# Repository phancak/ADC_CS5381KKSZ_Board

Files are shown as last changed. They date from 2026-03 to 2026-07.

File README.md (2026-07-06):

# 24-bit High-Fidelity Data Acquisition System
### High-SNR Analog Front-End & Mixed-Signal Instrumentation Platform

<div align="center">
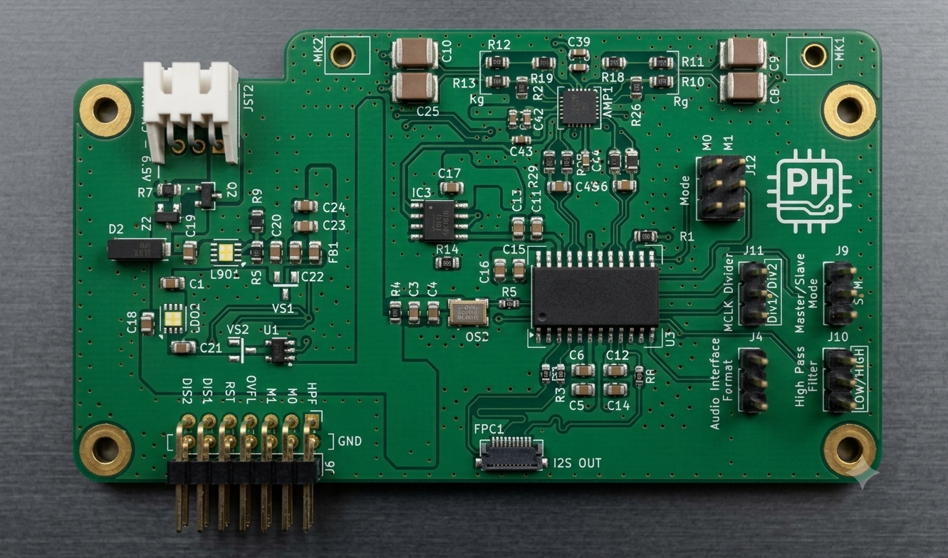
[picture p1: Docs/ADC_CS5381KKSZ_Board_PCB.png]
ADC CS5381KKSZ Board PCB 3D Render
  
  <br>
  <em>ADC CS5381KKSZ 4-layer PCB diagram.</em>
</div>

## 📑 Quick Access
* [**📂 View Project Schematics (PDF)**](./Schematics/ADC_CS5381KKSZ_Board_Schematics.pdf)

## 🚀 Overview
This project is a custom-designed, high-precision Analog-to-Digital Conversion (ADC) board optimized for professional audio and precision instrumentation. It utilizes a fully differential signal chain to maximize dynamic range and minimize common-mode noise, making it suitable for high-EMI environments.

## 🛠 Core Component Selection
* **ADC:** **CS5381K-KSZ** (120dB Dynamic Range, 24-bit, 192kHz sampling). A flagship Delta-Sigma converter.
* **Front-End Driver:** **ADA4940-2** Ultra-low noise, fully differential amplifier.
* **Sensors:** 2x **ICS-40730** Bottom-Port MEMS Microphones with 74dB SNR for high-definition acoustic capture.

---

## 🏗 Key Engineering Challenges & Solutions

### 1. Differential Signal Integrity
To leverage the 120dB SNR of the CS5381, I implemented a fully differential path from the amplifier to the ADC.
* **The Challenge:** Converting single-ended sensor signals while maintaining a -122dB SFDR.
* **The Solution:** Used the **ADA4940-2** to provide a stable common-mode voltage and high linearity, ensuring the ADC inputs stay within the optimal swing range.

### 2. Precision Length Matching (Via Compensation)
In high-speed mixed-signal design, phase coherency between channels is critical.
* **Via Propagation Delay:** One of my analog traces required two vias (unavoidable). To prevent phase shift, I calculated the vertical travel distance through the 1.6mm PCB stackup and compensated the "via-free" traces by adding **3.2mm of serpentine meanders**.
* **Tolerance:** Achieved sub-0.5mm effective electrical length matching across all high-priority analog traces.

### 3. Power Integrity & EMI Shielding
* **Copper Pours:** Utilized large 3.3V and 5V copper polygons on the top layer to minimize **IR drop** and **loop inductance**. 
* **Isolation:** Strategically distanced power pours from high-speed digital lines to prevent capacitive crosstalk. 
## 🏗 Grounding & Power Integrity Strategy
Unlike traditional "Split Plane" designs, this board utilizes a **Solid Ground Plane** strategy on internal layers 2 and 3 to ensure the lowest possible impedance for return currents.

* **Low-Inductance Return Paths:** By maintaining a continuous ground plane under the analog and digital sections, I minimized the loop area for high-speed I2S signals, preventing ground-bounce and radiated emissions.
* **Component Partitioning:** Rather than a physical split in the copper, I used **Spatial Isolation**. Analog components (ADA4940, CS5381 input stage) are physically grouped on one side of the board, while digital I/O and the STM32 interface are on the opposite side, ensuring digital return currents do not traverse the sensitive analog "quiet zone."
* **Layer Stackup:**
    * Layer 1: Signal / Power Pours
    * Layer 2: **GND (Solid Reference)**
    * Layer 3: **GND (Solid Reference)**
    * Layer 4: Signal / Power Pours
---

## 👨‍💻 About Me
I am an Engineering Graduate from the **University of British Columbia (UBC)**. I specialize in the intersection of Embedded Systems and Data Engineering. Whether it's designing 6-DoF robotic arms or high-fidelity ADC boards, I focus on "First Principles" engineering—calculating via delays, optimizing power pours, and ensuring data integrity from the sensor to the report.

---

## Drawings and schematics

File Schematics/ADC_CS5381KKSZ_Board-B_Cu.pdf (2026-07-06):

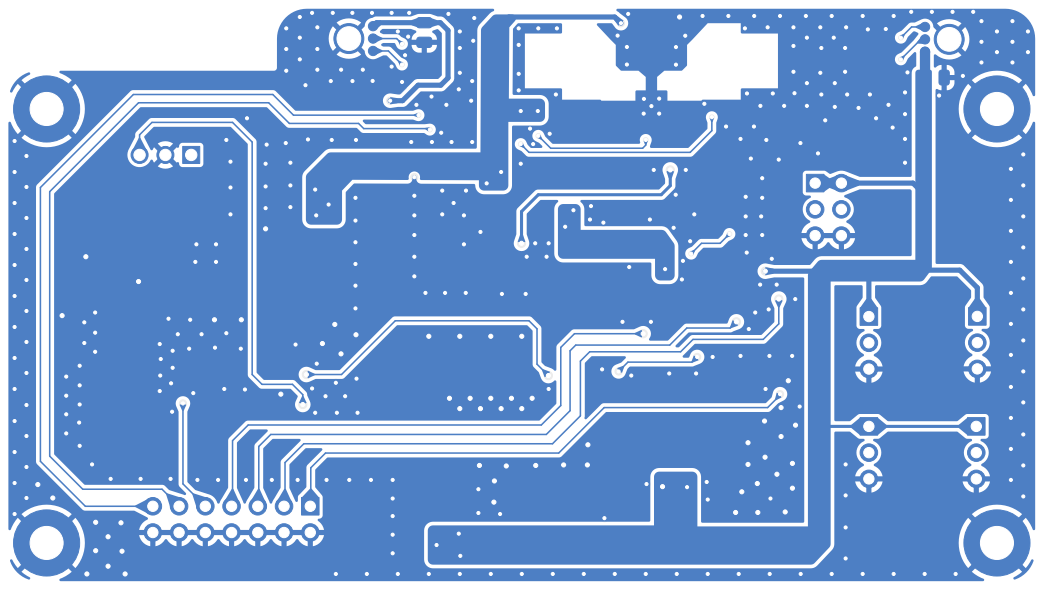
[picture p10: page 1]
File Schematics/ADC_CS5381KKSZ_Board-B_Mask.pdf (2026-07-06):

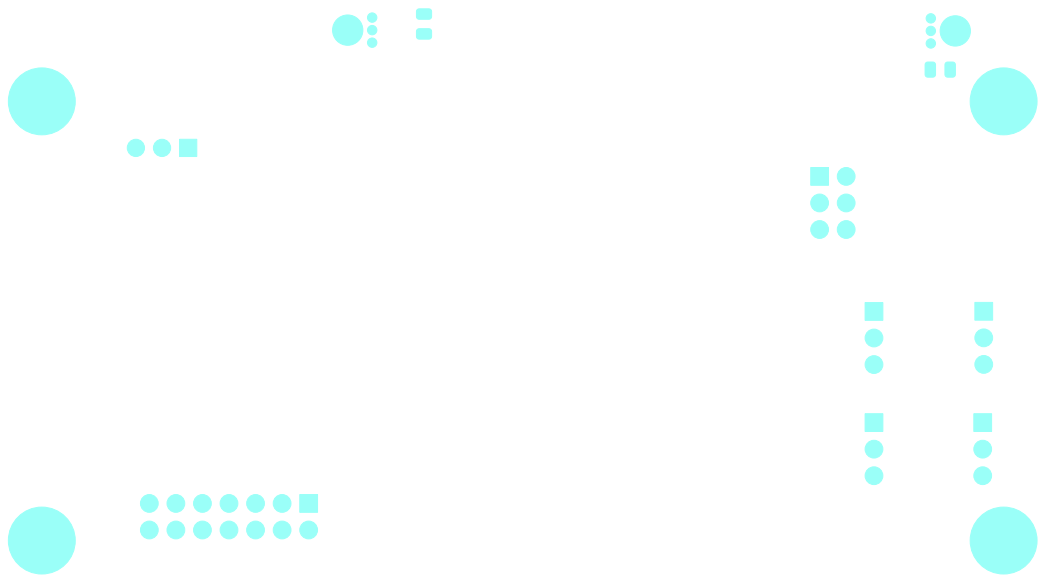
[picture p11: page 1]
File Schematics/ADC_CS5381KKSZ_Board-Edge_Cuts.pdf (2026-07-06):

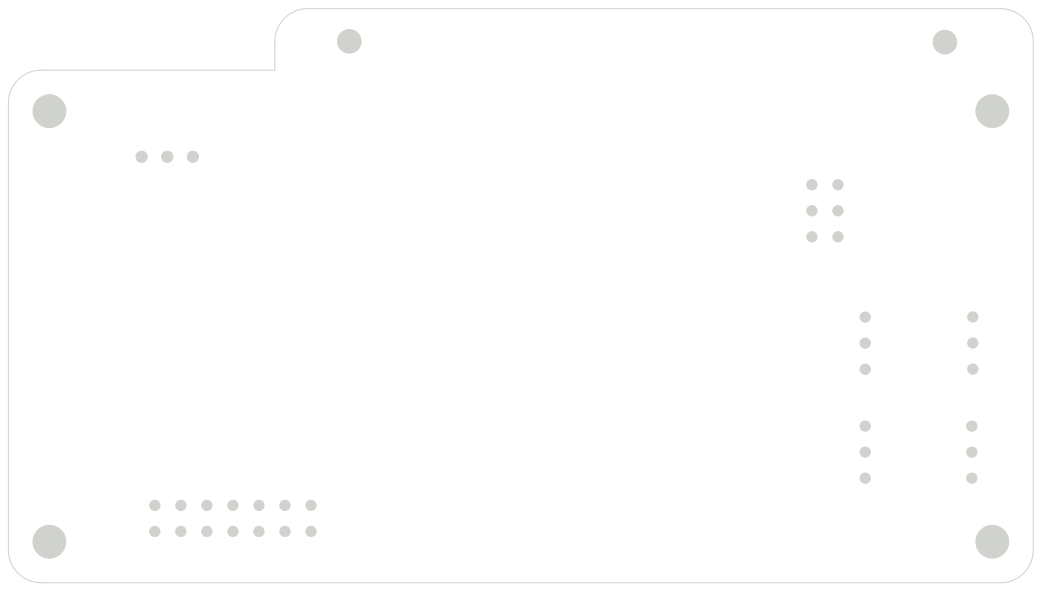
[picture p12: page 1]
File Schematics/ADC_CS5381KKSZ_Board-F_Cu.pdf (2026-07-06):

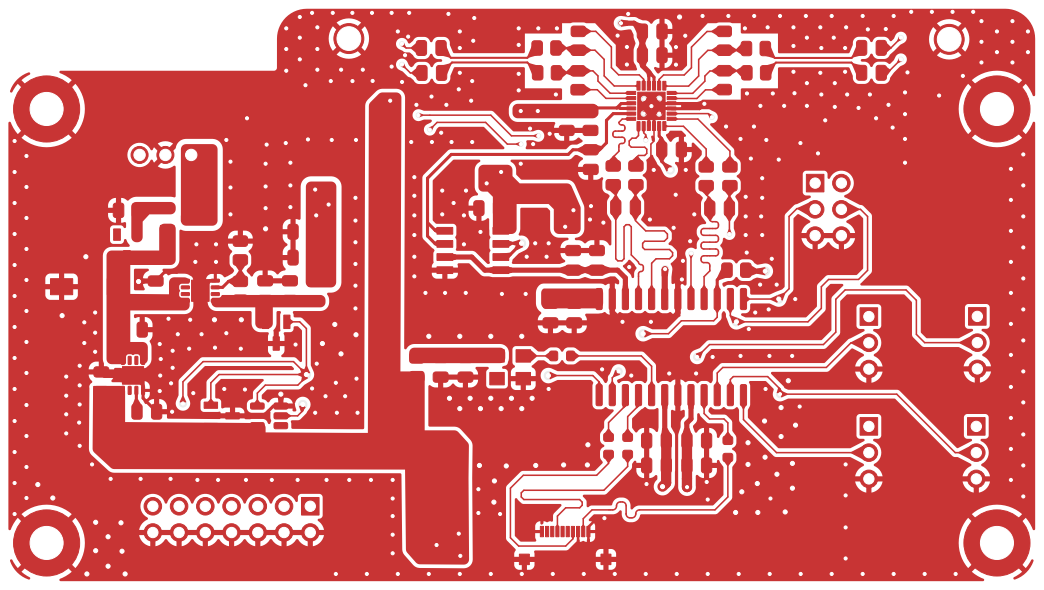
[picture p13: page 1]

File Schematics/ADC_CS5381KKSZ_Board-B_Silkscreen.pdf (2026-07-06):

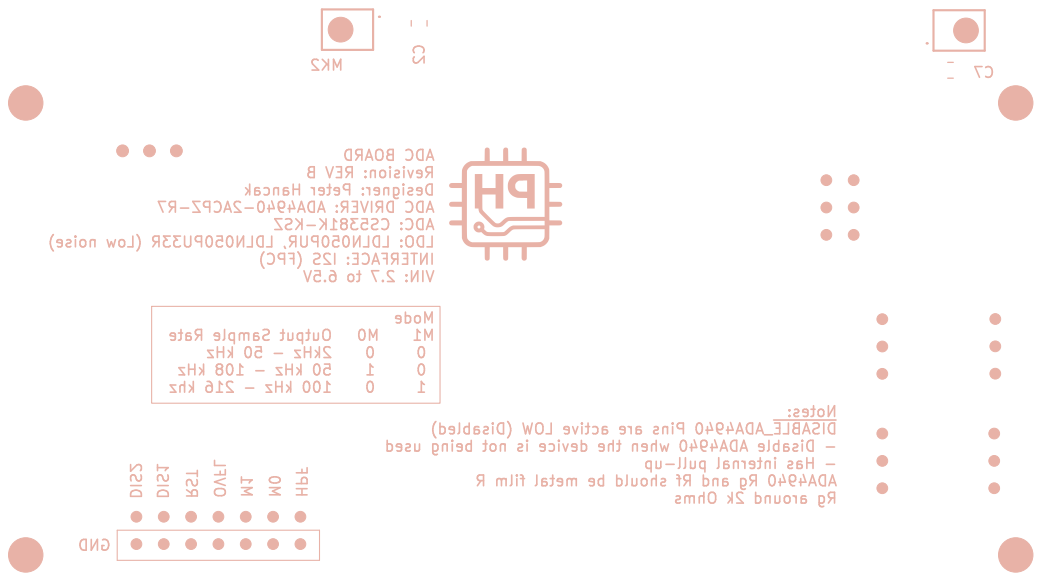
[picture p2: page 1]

used being not is device the when ADA4940 Disable - pull-up internal Has - R film metal be should Rf and Rg ADA4940 Ohms 2k around Rg M1 MK2 C7 C2

OVFL M0 GND RST BOARD ADC

B REV Revision: Hancak Peter Designer: ADA4940-2ACPZ-R7 DRIVER: ADC

CS5381K-KSZ ADC: noise) (Low LDLN050PU33R LDLN050PUR, LDO: (FPC) I2S INTERFACE: 6.5V to 2.7 VIN: HPF Mode Rate Sample Output M0 M1

khz 216 - kHz 100 0 1 DIS2 DIS1 Notes: (Disabled) LOW active are Pins ~{DISABLE}_ADA4940

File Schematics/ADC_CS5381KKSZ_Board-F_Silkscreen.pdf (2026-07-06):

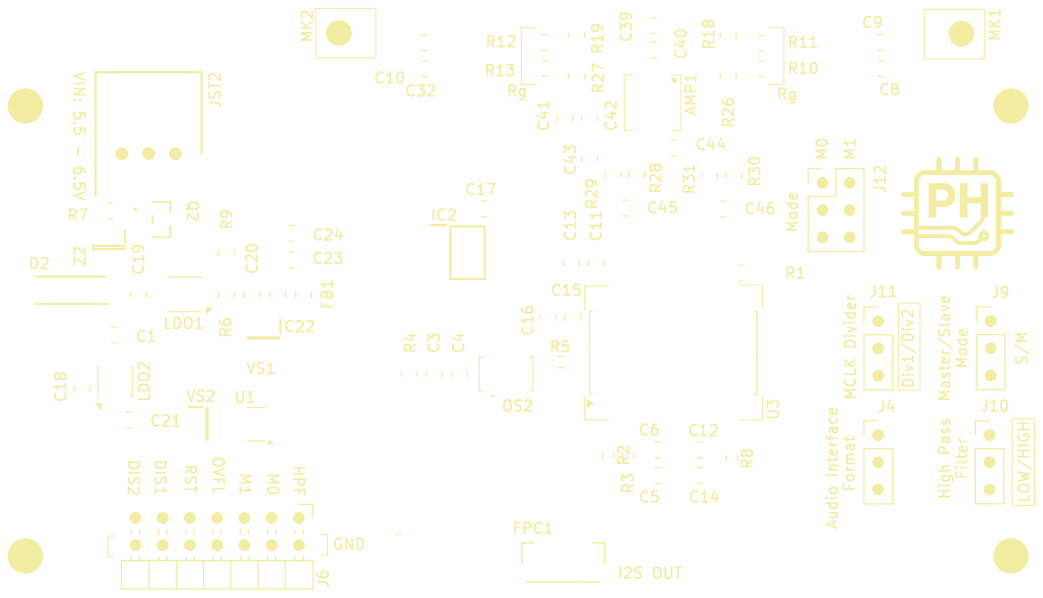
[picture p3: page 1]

LOW/HIGH MK2 M1 OVFL M0 Div1/Div2 High Pass Filter MCLK Divider Audio Interface Format RST Master/Slave Mode M0

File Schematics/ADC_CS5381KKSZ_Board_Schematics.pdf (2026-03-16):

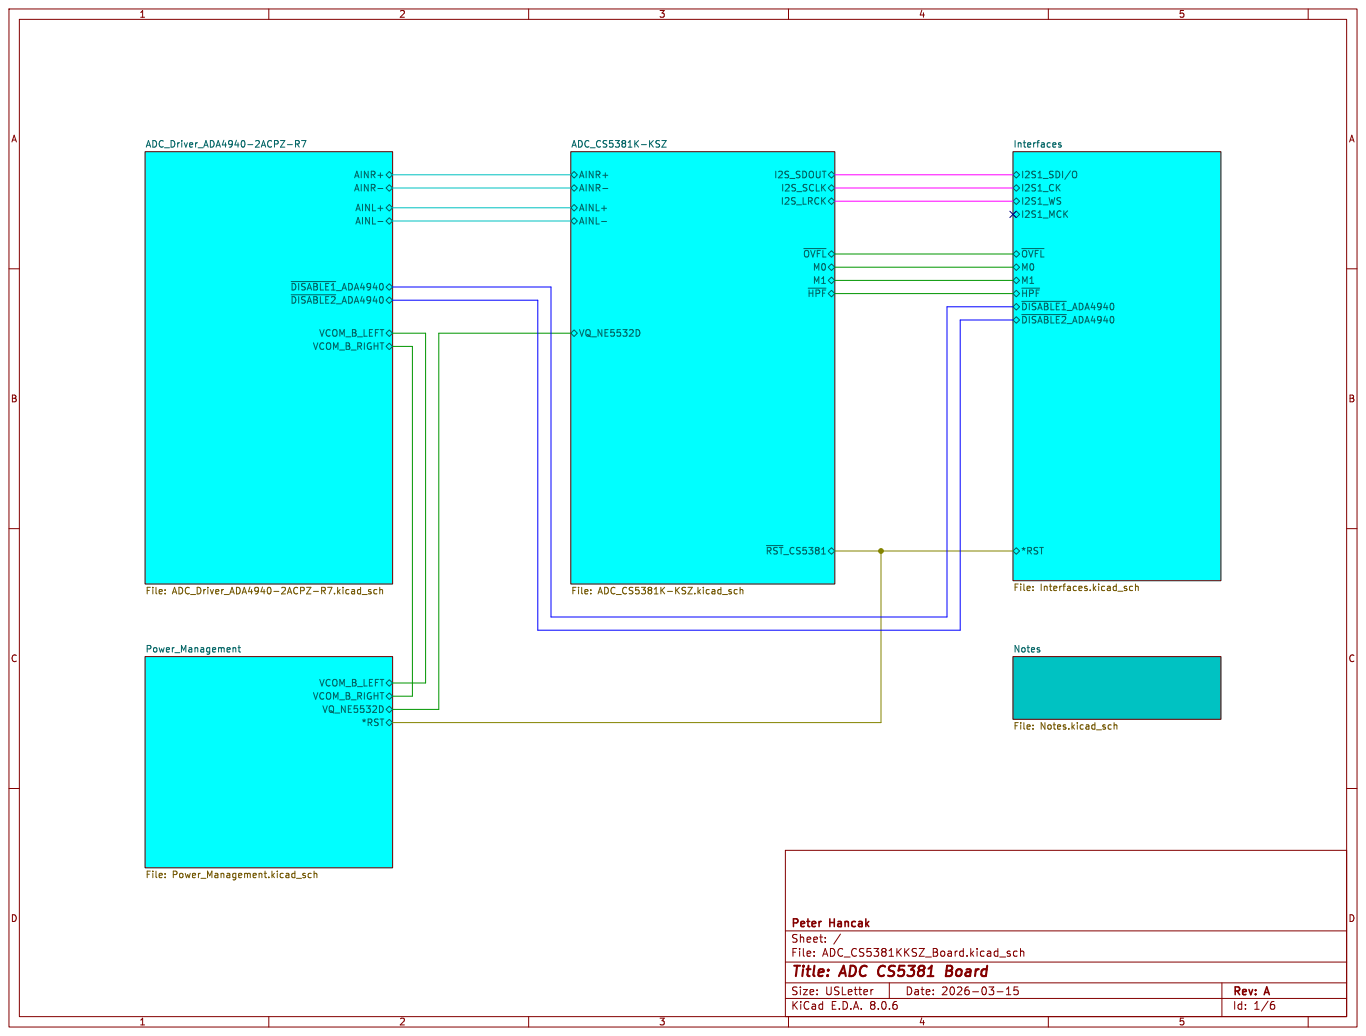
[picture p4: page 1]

Id: 1/6 Title: ADC CS5381 Board

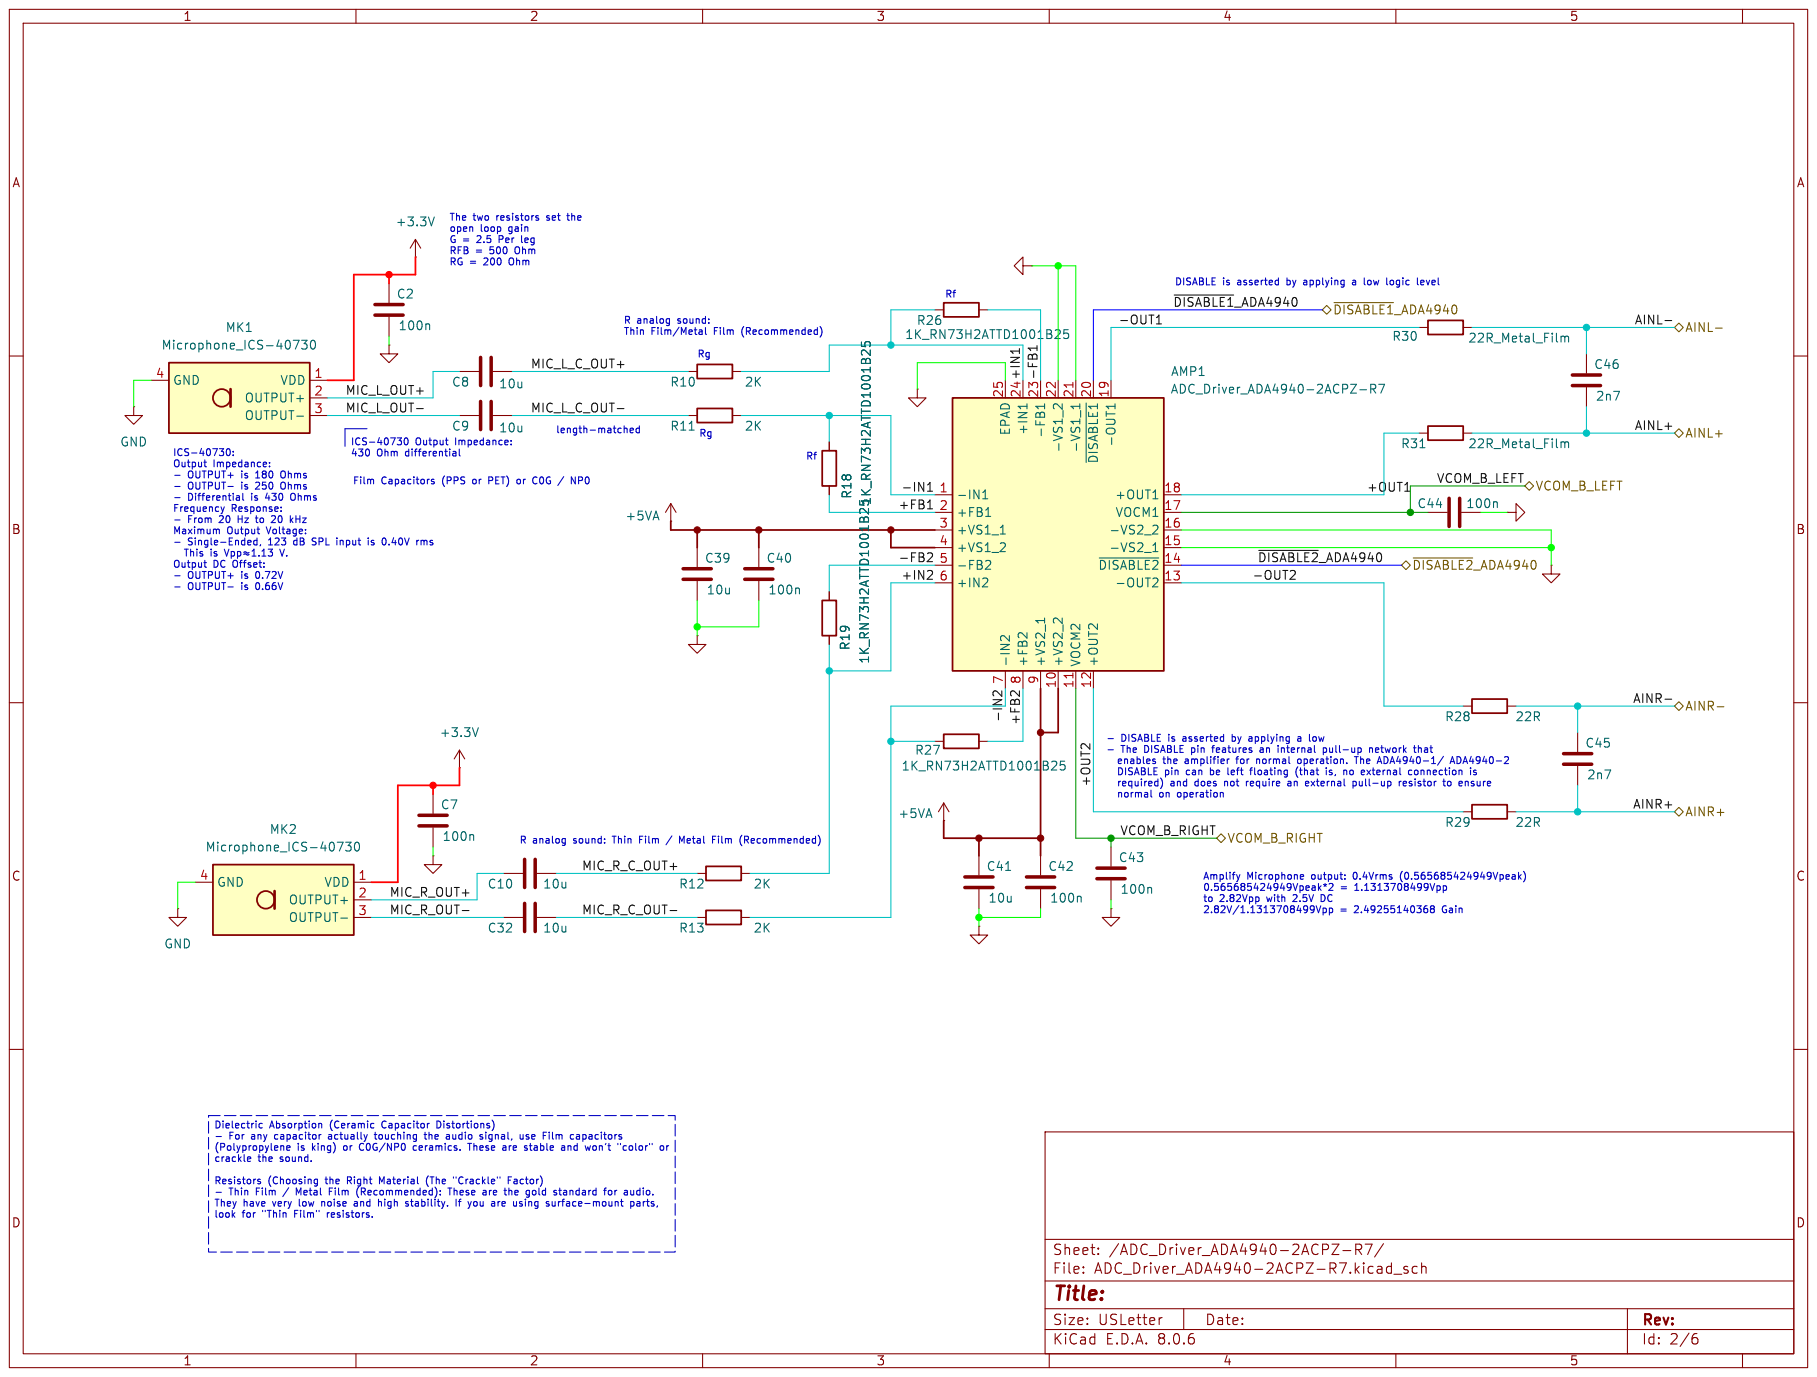
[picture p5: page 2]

open loop gain G = 2.5 Per leg RFB = 500 Ohm

ICS-40730: Output Impedance: - OUTPUT+ is 180 Ohms

Id: 2/6 Title: File: ADC_Driver_ADA4940-2ACPZ-R7.kicad_sch Sheet: /ADC_Driver_ADA4940-2ACPZ-R7/

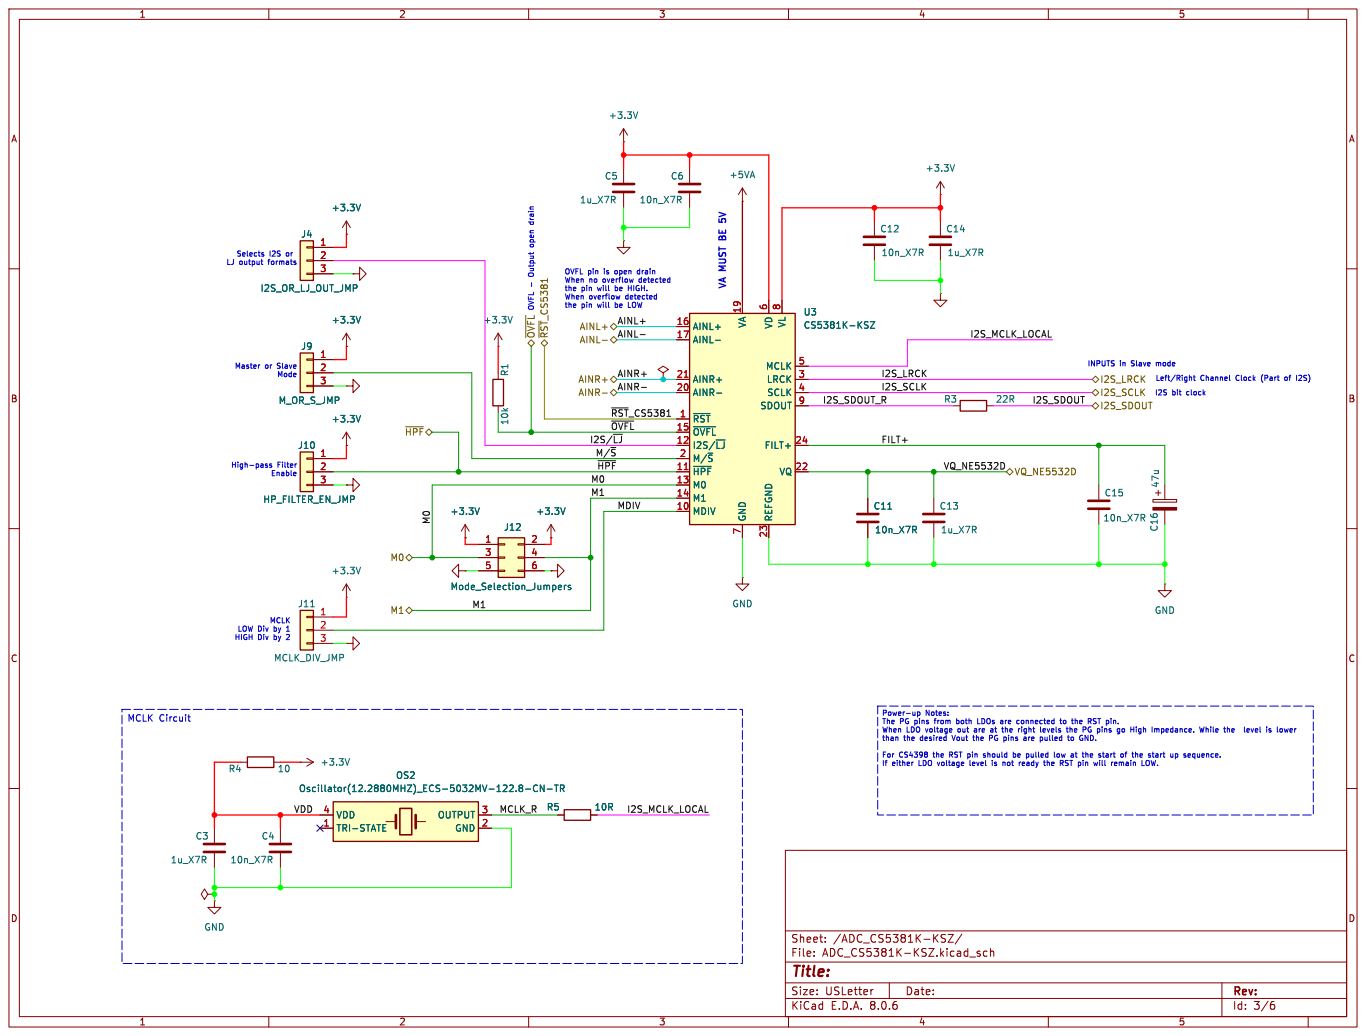
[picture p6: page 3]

- Output open drain Power-up Notes: The PG pins from both LDOs are connected to the RST pin. When LDO voltage out are at the right levels the PG pins go High Impedance. While the level is lower

~{RST}_CS5381 AINR- AINL+ AINL-
I2S_MCLK_LOCAL M0M/~{S}MDIV

INPUTS in Slave mode
I2S_LRCK

Id: 3/6 Title: File: ADC_CS5381K-KSZ.kicad_sch Sheet: /ADC_CS5381K-KSZ/ GND

than the desired Vout the PG pins are pulled to GND. For CS4398 the RST pin should be pulled low at the start of the start up sequence.

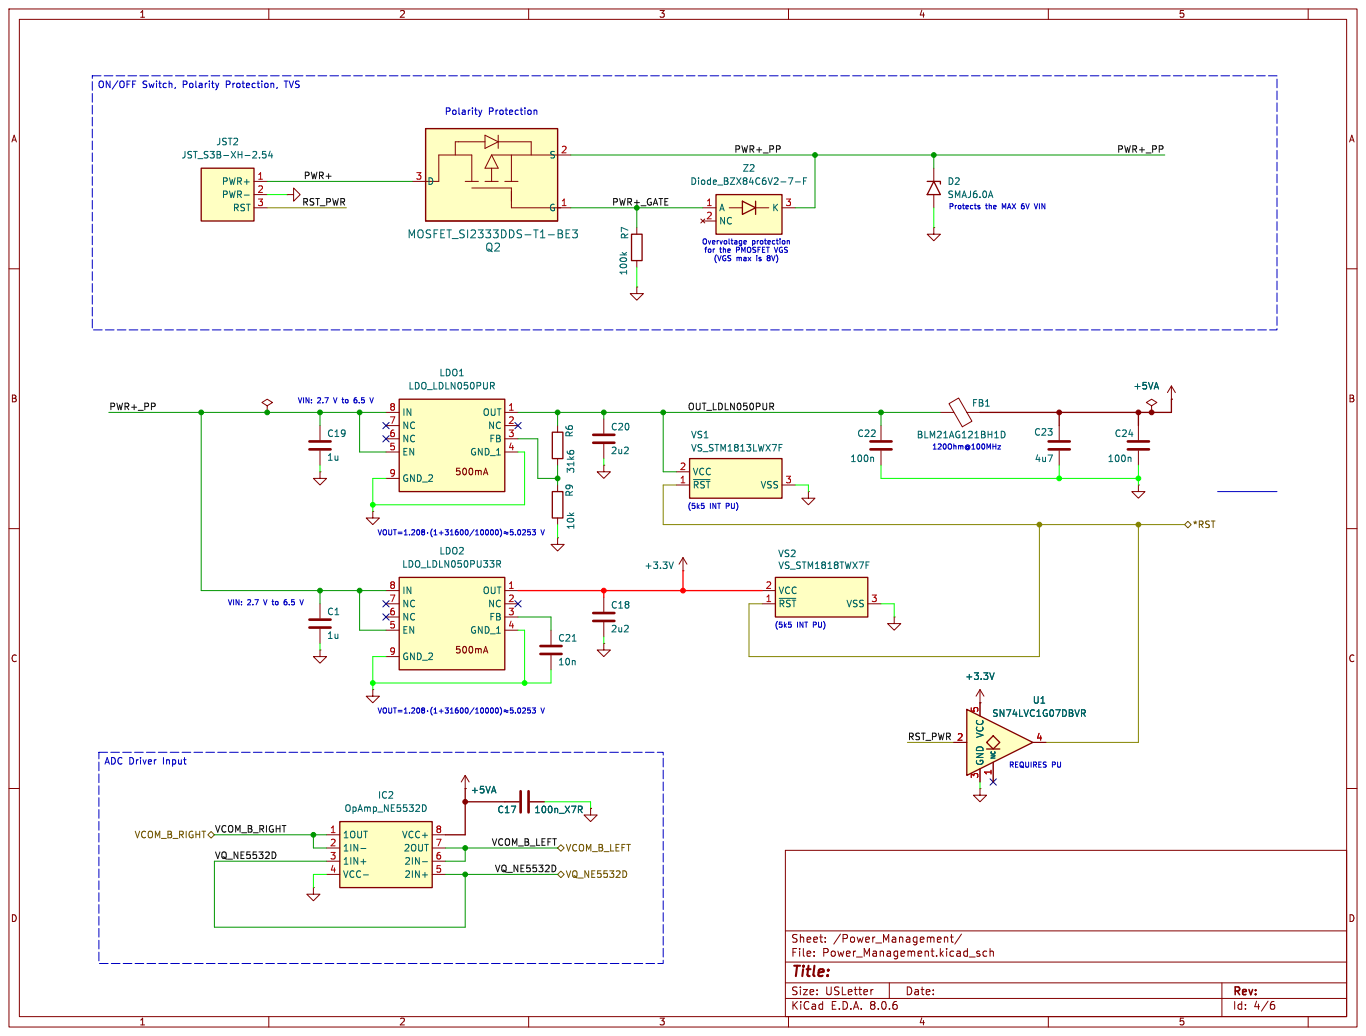
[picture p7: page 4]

for the PMOSFET VGS

Id: 4/6 Title: File: Power_Management.kicad_sch Sheet: /Power_Management/

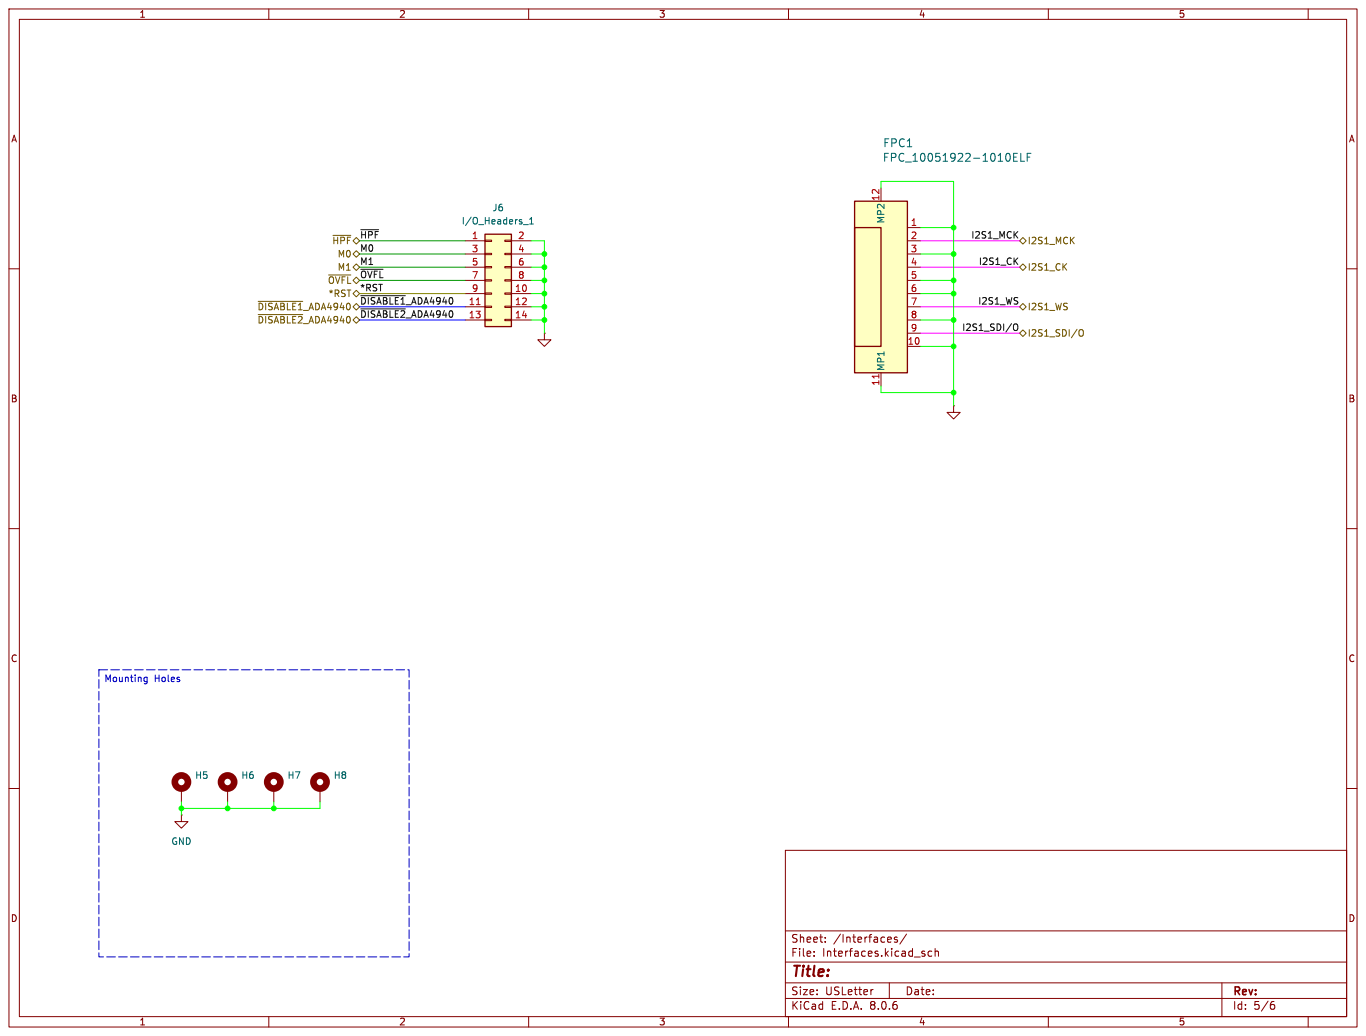
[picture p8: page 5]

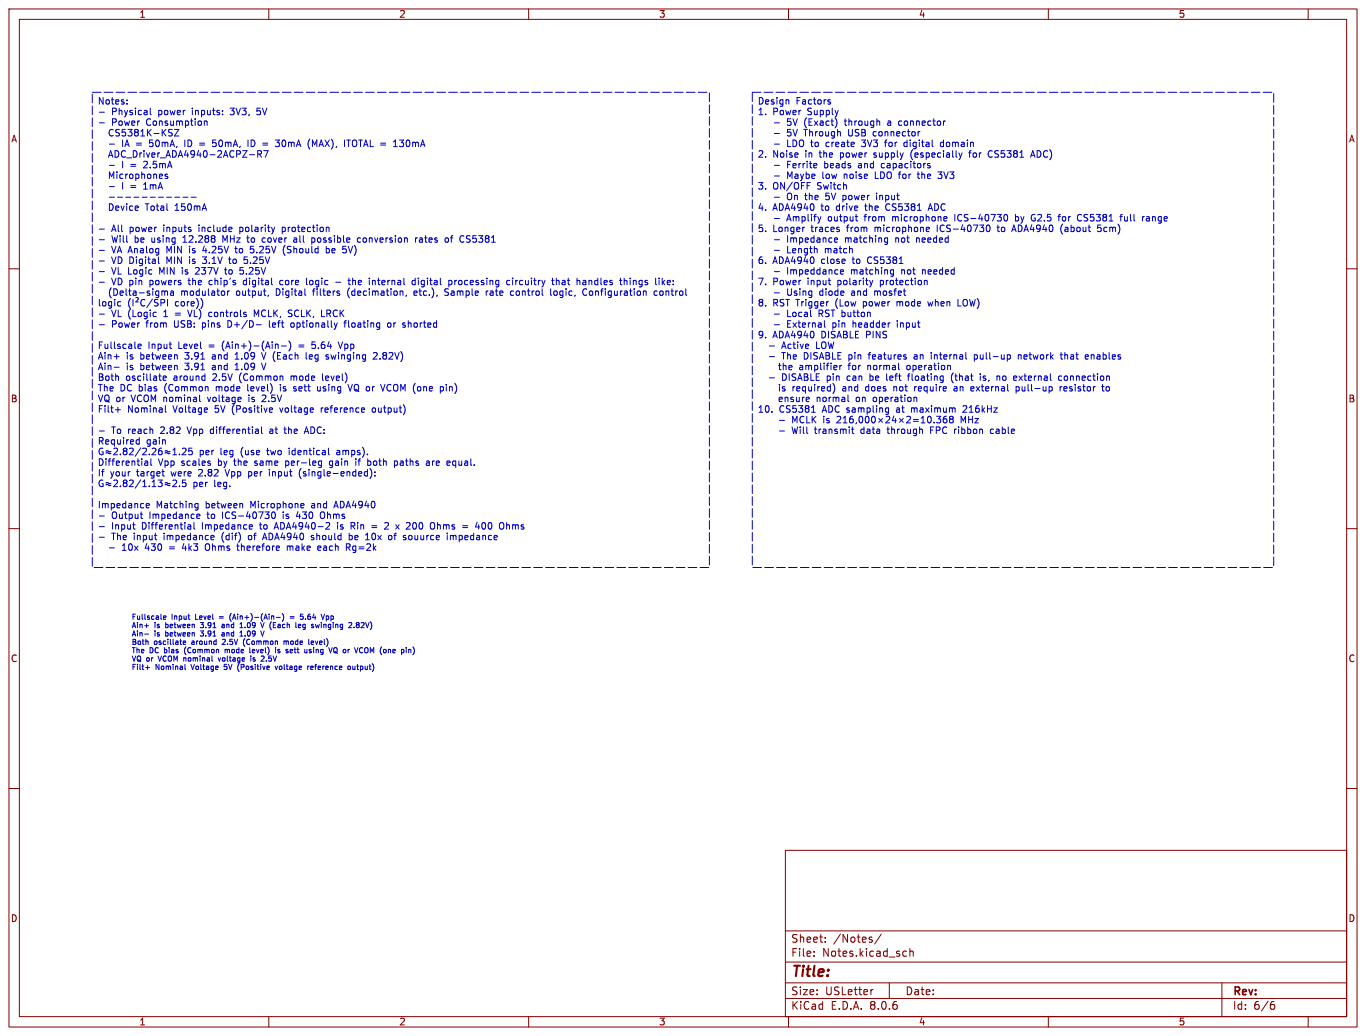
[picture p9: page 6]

Design Factors 1. Power Supply

- 5V (Exact) through a connector
- 5V Through USB connector
- Ferrite beads and capacitors
- Maybe low noise LDO for the 3V3
3. ON/OFF Switch
- On the 5V power input 4. ADA4940 to drive the CS5381 ADC

- IA = 50mA, ID = 50mA, ID = 30mA (MAX), ITOTAL = 130mA
ADC_Driver_ADA4940-2ACPZ-R7
- I = 2.5mA Microphones

- VA Analog MIN is 4.25V to 5.25V (Should be 5V)
- VD Digital MIN is 3.1V to 5.25V
- VL Logic MIN is 237V to 5.25V

- Length match
6. ADA4940 close to CS5381
- Using diode and mosfet 8. RST Trigger (Low power mode when LOW)

- Local RST button
- External pin headder input 9. ADA4940 DISABLE PINS

- Active LOW
ensure normal on operation
- MCLK is þÿ216,000×24×2=10.368 MHz

If your target were 2.82 Vpp per input (single-ended):
þÿG"H2.82/1.13"H2.5 per leg.

Id: 6/6 Title: File: Notes.kicad_sch Sheet: /Notes/
